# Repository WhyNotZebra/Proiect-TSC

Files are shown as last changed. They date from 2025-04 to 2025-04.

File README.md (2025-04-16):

# Proiect TSC – E-Reader Hardware

Acest proiect își propune să construiască un **e-reader open-source**, bazat pe microcontrollerul **ESP32-C6**, cu un display **e-Paper de 7.5"**, o baterie **Li-Po** reîncărcabilă și conexiuni **Wi-Fi/BLE**.  
Scopul este obținerea unui dispozitiv cu **consum de energie redus**, ideal pentru citirea de cărți și documente în format electronic.

---

## Cuprins

- [Diagrama bloc](#diagrama-bloc)
- [Bill of Materials (BOM)](#bill-of-materials-bom)
- [Descriere hardware și funcționalitate](#descriere-hardware-și-funcționalitate)
  - [Microcontroller – ESP32-C6](#microcontroller--esp32-c6)
  - [Ecran e-Paper (7.5")](#ecran-e-paper-75)
  - [Alimentare și baterie](#alimentare-și-baterie)
  - [Buton / BOOT](#buton--boot)
  - [Consum și durată baterie](#consum-și-durată-baterie)
- [Pin Mapping ESP32-C6](#pin-mapping-esp32-c6)
- [Cum să începi (Software)](#cum-să-începi-software)
- [Randări și fișiere CAD](#randări-și-fișiere-cad)
- [Observații de proiectare](#observații-de-proiectare)
- [Licență și contribuții](#licență-și-contribuții)
- [Referințe](#referințe)
- [Concluzie](#concluzie)

---

## Diagrama bloc

Fișierul **block_diagram.png** descrie schema generală a sistemului, incluzând:

- **ESP32-C6** – Microcontroller principal  
- **Ecran e-Paper** – Interfață SPI  
- **Baterie Li-Po + modul de încărcare**  
- **Conectivitate USB** pentru încărcare și date  
- **Buton/Buton BOOT** pentru interacțiunea cu utilizatorul (reset, mod debug etc.)  

---

## Bill of Materials (BOM)

Mai jos este prezentată o listă cu principalele componente folosite în proiect. Pentru toate componentele, datasheet-urile sunt indicate pentru a facilita selectarea și verificarea specificațiilor.

| Referință | Valoare / Cod | Dispozitiv / Tip | Descriere | Link / Datasheet |
|---|---|---|---|---|
| **ESP32-C6** | ESP32-C6-DevKitC-1 | Placă DevKitC-1 ESP32-C6 | Microcontroller Wi-Fi 6 + BLE 5 | [Mouser Link](https://ro.mouser.com/ProductDetail/Espressif-Systems/ESP32-C6?qs=Imq1NPwxi75noDtUpuVuWw%3D%3D)  |
| **Ecran e-Paper** | 7.5" Waveshare V2 | Interfață SPI | Afișaj E-Ink 800×480 | [Waveshare Link](https://www.waveshare.com/7.5inch-e-paper-hat.htm) |
| **Baterie Li-Po** | 3.7V / 1800mAh | Cellevia LP584174 (ex.)  | Sursă portabilă de alimentare | [Exemplu Link](https://ampul.eu/ro/baterii/5519-baterie-li-pol-150mah-37v-302025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) |
| **Modul încărcare** | TP4056 / similar | TP4056 | Încărcare baterie Li-Po via USB | [TP4056 Link](https://ro.mouser.com/ProductDetail/DFRobot/DFR0668?qs=yqaQSyyJnNgw1QAWGbVsjg%3D%3D) |
| **Regulator LDO** | AMS1117-3.3V | SOT223 / SOT25 | Stabilizator 3.3V | [AMS1117 Link](https://ro.mouser.com/ProductDetail/Seeed-Studio/105020001?qs=1%252B9yuXKSi8Cg%2Fkz%252BrjYoTQ%3D%3D) |
| **Buton push** | PBS-110 / BOOT_BTN | 6×6mm tact switch | Buton de interacțiune (reset, BOOT) | [Omron B3F Link](https://ro.mouser.com/ProductDetail/Omron-Electronics/B3FS-1095P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) |
| **Diverse** | Condensatori, rezistențe, diode TVS, conectori USB-C, etc. | - | Pentru filtre, protecție și fixare tensiune | Vezi fișierul complet BOM din repository |

---

## Descriere hardware și funcționalitate

### Microcontroller – ESP32-C6
- Oferă **conectivitate Wi-Fi 6** și **Bluetooth 5**.  
- Gestionează afișajul e-paper prin **SPI**.  
- Are GPIO-uri disponibile pentru interacțiuni suplimentare (buton, senzori etc.).  

### Ecran e-Paper (7.5")
- **Rezoluție**: 800×480 pixeli.  
- **Consum foarte redus** în mod static (menține imaginea fără consum suplimentar).  
- **Interfață SPI** pentru actualizare.  
- Ideal pentru citirea textelor mari datorită contrastului ridicat și lipsei de flicker.  

### Alimentare și baterie
- **Baterie Li-Po** de 3.7V, 1800mAh (sau altă capacitate, la alegere).  
- **Încărcare prin USB (5V)** cu modul dedicat (TP4056 sau similar).  
- **Regulator LDO (3.3V)** pentru alimentarea ESP32-C6 și a perifericelor.  

### Buton / BOOT
- Permite **resetarea** microcontrollerului, intrarea în **mod de programare** sau alte interacțiuni definite de utilizator (ex. schimbare pagină, meniu etc.).  

### Consum și durată baterie
- În mod de citire (fără actualizări frecvente), **e-paper** consumă extrem de puțin.  
- În momentul schimbării paginii (actualizare e-paper), consumul crește pentru scurt timp.  
- **Estimare durată baterie**: de la câteva zile la câteva săptămâni, în funcție de frecvența actualizărilor și de modul de somn (sleep) al ESP32-C6.  

---

## Pin Mapping ESP32-C6

Tabelul de mai jos prezintă pinii importanți folosiți în proiect pentru conectarea ecranului e-paper și a butonului:

| Funcționalitate | Pin ESP32-C6  | Descriere |
|---|---|---|
| **SPI CLK** | GPIO6 | Semnal de ceas SPI |
| **SPI MOSI** | GPIO7 | Linie de date |
| **E-Paper CS**  | GPIO10 | Chip Select display |
| **E-Paper DC**  | GPIO5 | Selectare date/command |
| **E-Paper RST** | GPIO4 | Reset pentru e-paper |
| **E-Paper BUSY**| GPIO3 | Linie READY (ocupat) |
| **Buton** | GPIO0/1 etc. | Buton reset/interacțiune  |
| **UART TX/RX**  | GPIO21/20 | Debug (opțional) |

> **Notă**: Pinii pot fi modificați în funcție de necesități. Tabelul de mai sus reprezintă doar un exemplu.  

---

## Cum să începi (Software)

1. **Clonează repository-ul**:
    ```bash
    git clone https://github.com/WhyNotZebra/Proiect-TSC.git
    ```

2. **Instalează suportul** pentru **ESP32-C6** în mediul de dezvoltare (Arduino IDE sau PlatformIO).  
   - Asigură-te că ai ultima versiune de **ESP32 Boards** în Arduino IDE / PlatformIO.

3. **Deschide folderul** cu codul sursă (ex. `software/`) în Arduino IDE / PlatformIO.  
   - Exemple de librării necesare:  
     - `Adafruit-GFX`  
     - `GxEPD2` (sau altă librărie dedicată e-paper)

4. **Selectează placa** corespunzătoare (ex. *ESP32C6 DevKit*) și conectează placa prin USB.

5. **Încărcă (upload)** sketch-ul pe microcontroller.

6. **Monitorizează** comportamentul în *Serial Monitor* (viteză tipică: 115200 bps) pentru log-uri de debug.

---

## Randări și fișiere CAD

- Folderul `Images/` conține randări 3D (`render_device.png`, `render_pcb.png`) și diagrama bloc (`block_diagram.png`).  
- Fișierele de design (Eagle, KiCad sau Fusion 360 PCB) se află în folderul `hardware/`.  
- Gerbers și BOM detaliată pentru fabricație se găsesc în `hardware/output/`.  

---

## Observații de proiectare

- **Consum redus**: e-paper-ul menține imaginea fără consum suplimentar, deci microcontrollerul poate intra des în mod *sleep*.  
- **Protecția la încărcare**: modului de încărcare TP4056 i se pot adăuga circuite de protecție suplimentare (TVS, diode) pe portul USB-C.  
- **Dimensiuni și ergonomie**: poziționarea butoanelor de navigare la îndemână îmbunătățește experiența de lectură.  

---

## Licență și contribuții

Acest proiect este disponibil sub licența **MIT** (sau alta specificată în repository).  
Orice contribuții (pull request-uri, issue-uri) sunt încurajate, fie că este vorba de:
- Optimizări hardware  
- Îmbunătățiri de cod  
- Documentație suplimentară  
- Orice alt element care poate aduce valoare proiectului  

---

## Referințe

- [Documentația oficială ESP32-C6](#)  
- [TP4056 Battery Charger Datasheet](#)  

---

## Concluzie

Proiectul **TSC – E-Reader Hardware** oferă o platformă completă pentru a crea un dispozitiv de citire electronică cu autonomie ridicată și hardware flexibil.  
Fie că vrei să înveți, să experimentezi sau să creezi propriul tău eReader personalizat, acest repository îți pune la dispoziție:

- **Schemă și layout PCB**  
- **BOM detaliată**  
- **Cod sursă configurabil**  
- **Documentație pas cu pas**

Spor la **cafelutza**!

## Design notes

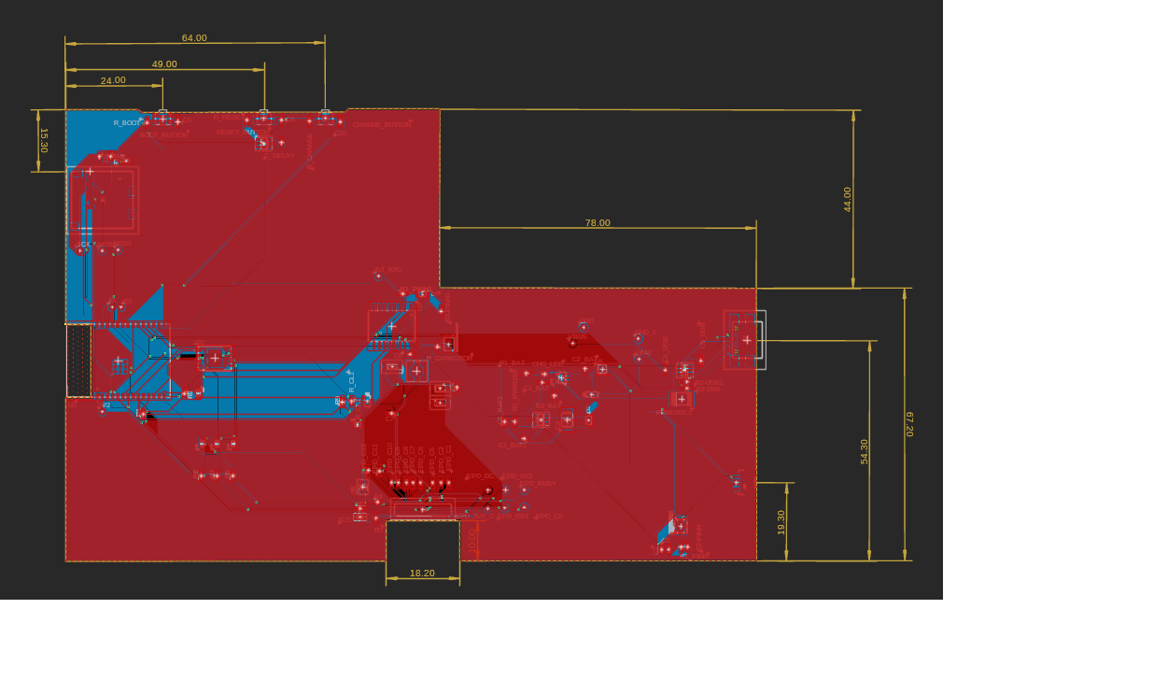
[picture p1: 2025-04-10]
Images/BRD.png

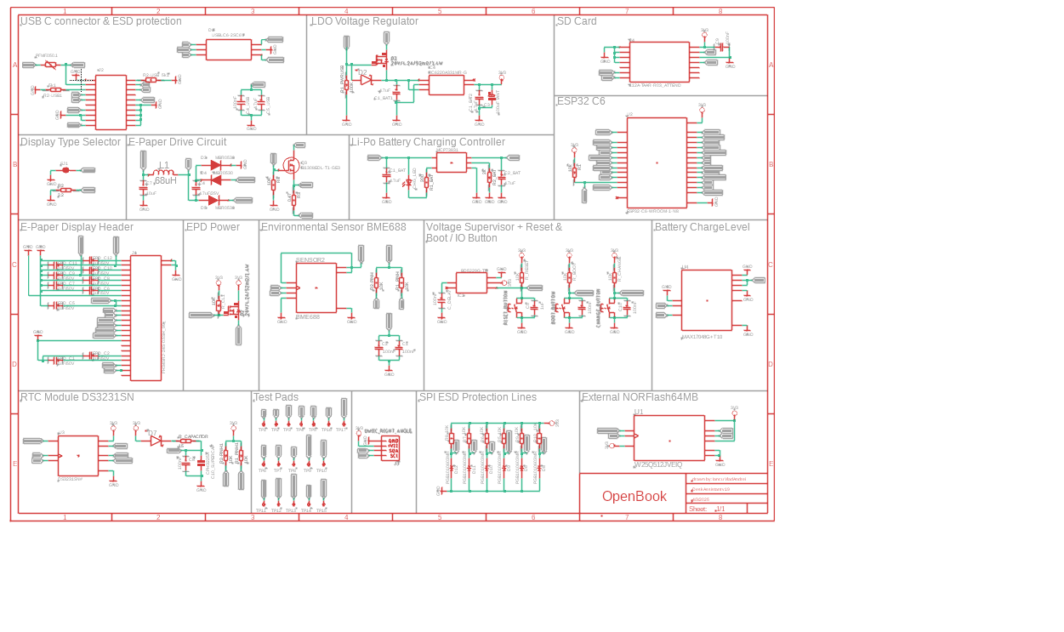
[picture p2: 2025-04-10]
Images/SCH.png

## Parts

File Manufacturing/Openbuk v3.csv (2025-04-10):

Part | Value | Device | Footprint Name | Detailed Description
BOOT_BUTTON |  | BUTTON_CUSYOMV1 | MYBUTTON
C1 | 100nF | EAGLE-LTSPICE_CC0402 | EAGLE-LTSPICE_C0402 | CAPACITOR, European symbol
C1_BAT | 4.7uF | EAGLE-LTSPICE_CC0402 | EAGLE-LTSPICE_C0402 | CAPACITOR, European symbol
C1_BAT1 | 4.7uF | EAGLE-LTSPICE_CC0402 | EAGLE-LTSPICE_C0402 | CAPACITOR, European symbol
C1_BAT2 | 4.7uF | EAGLE-LTSPICE_CC0402 | EAGLE-LTSPICE_C0402 | CAPACITOR, European symbol
C2 | 100nF | EAGLE-LTSPICE_CC0402 | EAGLE-LTSPICE_C0402 | CAPACITOR, European symbol
C2_BAT | 4.7uF | EAGLE-LTSPICE_CC0402 | EAGLE-LTSPICE_C0402 | CAPACITOR, European symbol
C3 | 100uF TANT | RCL_CPOL-EUCT3528 | RCL_CT3528 | POLARIZED CAPACITOR, European symbol
C4 | 4.7uF/25V | EAGLE-LTSPICE_CC0402 | EAGLE-LTSPICE_C0402 | CAPACITOR, European symbol
C4_USB | 100nF | EAGLE-LTSPICE_CC0402 | EAGLE-LTSPICE_C0402 | CAPACITOR, European symbol
C5 | 1uF | EAGLE-LTSPICE_CC0402 | EAGLE-LTSPICE_C0402 | CAPACITOR, European symbol
C5_USB | 4.7uF | EAGLE-LTSPICE_CC0402 | EAGLE-LTSPICE_C0402 | CAPACITOR, European symbol
C6 | 100nF | EAGLE-LTSPICE_CC0402 | EAGLE-LTSPICE_C0402 | CAPACITOR, European symbol
C7 | 10uF | EAGLE-LTSPICE_CC0402 | EAGLE-LTSPICE_C0402 | CAPACITOR, European symbol
C8 | 100nF | EAGLE-LTSPICE_CC0402 | EAGLE-LTSPICE_C0402 | CAPACITOR, European symbol
C9 | 100nF | EAGLE-LTSPICE_CC0402 | EAGLE-LTSPICE_C0402 | CAPACITOR, European symbol
C10 | 100nF | EAGLE-LTSPICE_CC0402 | EAGLE-LTSPICE_C0402 | CAPACITOR, European symbol
C10_SUPERCAP | CPH3225A | CPH3225A | CAPCP3225X100N | Cap 0.011F 3.3V 1210 Flat Check availability
CHANGE_BUTTON |  | BUTTON_CUSYOMV1 | MYBUTTON
CHG_LED |  | ADAFRUIT_LEDCHIP-LED0603 | ADAFRUIT_CHIP-LED0603 | LED
C_DELAY | 100nF | EAGLE-LTSPICE_CC0402 | EAGLE-LTSPICE_C0402 | CAPACITOR, European symbol
D1 | USBLC6-2SC6Y | USBLC6-2SC6Y | SOT95P280X145-6N | Low Cap. ESD Protection Auto SOT-23-6 STMicroelectronics USBLC6-2SC6Y, Dual Uni-Directional TVS Diode Array, 6-Pin SOT-23
D2 | SD0805S020S1R0 | ESP32_WROVER_AVX---SD0805S020S1R0_AVX_SD0805S020S1R0_0_0AVX_SD0805S020S1R0_0_0 | ESP32_WROVER_AVX---SD0805S020S1R0_AVX_SD0805S020S1R0_0 | Schottky Barrier Rectifier Diode
D3 | MBR0530 | MBR0530 | SOD3716X135N | ON SEMICONDUCTOR - MBR0530 - DIODE, SCHOTTKY, 0.5A, 30V, SOD-123
D4 | MBR0530 | MBR0530 | SOD3716X135N | ON SEMICONDUCTOR - MBR0530 - DIODE, SCHOTTKY, 0.5A, 30V, SOD-123
D5 | MBR0530 | MBR0530 | SOD3716X135N | ON SEMICONDUCTOR - MBR0530 - DIODE, SCHOTTKY, 0.5A, 30V, SOD-123
D6 | PGB1010603MR | PGB1010603MR | DIOC1608X36N | Check availability
D7 | SD0805S020S1R0 | ESP32_WROVER_AVX---SD0805S020S1R0_AVX_SD0805S020S1R0_0_0AVX_SD0805S020S1R0_0_0 | ESP32_WROVER_AVX---SD0805S020S1R0_AVX_SD0805S020S1R0_0 | Schottky Barrier Rectifier Diode
D8 | PGB1010603MR | PGB1010603MR | DIOC1608X36N | Check availability
D9 | PGB1010603MR | PGB1010603MR | DIOC1608X36N | Check availability
D10 | PGB1010603MR | PGB1010603MR | DIOC1608X36N | Check availability
D11 | PGB1010603MR | PGB1010603MR | DIOC1608X36N | Check availability
D12 | PGB1010603MR | PGB1010603MR | DIOC1608X36N | Check availability
EPD_C1 | 1uF/50V | EAGLE-LTSPICE_CC0402 | EAGLE-LTSPICE_C0402 | CAPACITOR, European symbol
EPD_C2 | 1uF/50V | EAGLE-LTSPICE_CC0402 | EAGLE-LTSPICE_C0402 | CAPACITOR, European symbol
EPD_C5 | 1uF/50V | EAGLE-LTSPICE_CC0402 | EAGLE-LTSPICE_C0402 | CAPACITOR, European symbol
EPD_C6 | 1uF/50V | EAGLE-LTSPICE_CC0402 | EAGLE-LTSPICE_C0402 | CAPACITOR, European symbol
EPD_C7 | 1uF/50V | EAGLE-LTSPICE_CC0402 | EAGLE-LTSPICE_C0402 | CAPACITOR, European symbol
EPD_C8 | 1uF/50V | EAGLE-LTSPICE_CC0402 | EAGLE-LTSPICE_C0402 | CAPACITOR, European symbol
EPD_C9 | 1uF/50V | EAGLE-LTSPICE_CC0402 | EAGLE-LTSPICE_C0402 | CAPACITOR, European symbol
EPD_C10 | 1uF/50V | EAGLE-LTSPICE_CC0402 | EAGLE-LTSPICE_C0402 | CAPACITOR, European symbol
EPD_C11 | 1uF/50V | EAGLE-LTSPICE_CC0402 | EAGLE-LTSPICE_C0402 | CAPACITOR, European symbol
EPD_C12 | 1uF/50V | EAGLE-LTSPICE_CC0402 | EAGLE-LTSPICE_C0402 | CAPACITOR, European symbol
IC1 | BD5229G-TR | BD5229G-TR | SOT95P280X125-5N | Voltage Detector with Adjustable Delay Time: CMOS processes are utilized to develop high precision, low current consumption CMOS reset ICs that allow arbitrary setting of the delay time. The extensive lineup includes both Nch Open Drain and CMOS output types in a wide range of detection voltages (from 2.3V to 6.0V, in 0.1V steps), enabling selection of the ideal solution based on customer requirements. In addition, the entire series is of course both lead-free and RoHS-compliant.
IC4 | XC6220A331MR-G | XC6220A331MR-G | SOT95P280X120-5N | LDO Voltage Regulators
J1 | FH34SRJ-24S-0.5SH_99_ | FH34SRJ-24S-0.5SH_99_ | FH34SRJ24S05SH99 | 24 Position FFC, FPC Connector Contacts, Top and Bottom 0.020 (0.50mm) Surface Mount, Right Angle"
J2 |  | SAMACSYS_PARTS_USB4110-GF-A | SAMACSYS_PARTS_USB4110GFA | CONN USB 2.0 TYPE-C R/A SMT
J3 | QWIIC_RIGHT_ANGLE | QWIIC_CONNECTORJS-1MM | JST04_1MM_RA | SparkFun I2C Standard Qwiic Connector
J4 | 112A-TAAR-R03_ATTEND | 112A-TAAR-R03_ATTEND | 112ATAARR03ATTEND | Micro SD Card Socket, Push-Push Type, Top Mount, SMT, H=1.83mm, 10u
L1 | 68uH | 744043680IND_4828-WE-TPC_WRE | IND_4828-WE-TPC_WRE
MCP73831 |  | ESP32_WROVER_SPARKFUN-IC-POWER_MCP73831 | ESP32_WROVER_SPARKFUN-IC-POWER_SOT23-5 | MCP73831T Li-Ion, Li-Pol Controller
PFMF.050.1 |  | ESP32C6_VARISTORCN1812 | ESP32C6_VARISTOR_CT/CN1812 | VARISTOR
Q1 | 20V/4.2A/52mO/1.4W | ESP32_WROVER_SPARKFUN-DISCRETESEMI_MOSFET_PCH-DMG2305UX-7 | ESP32_WROVER_SPARKFUN-DISCRETESEMI_SOT23-3 | P-channel MOSFETs
Q2 | 20V/4.2A/52mO/1.4W | ESP32_WROVER_SPARKFUN-DISCRETESEMI_MOSFET_PCH-DMG2305UX-7 | ESP32_WROVER_SPARKFUN-DISCRETESEMI_SOT23-3 | P-channel MOSFETs
Q3 | SI1308EDL-T1-GE3 | SI1308EDL-T1-GE3 | SOT65P210X110-3N | MOSFET N-Ch 30V 1.5A TrenchFET SC70 Vishay Si1308EDL-T1-GE3 N-channel MOSFET Transistor, 1.5 A, 30 V, 3-Pin SC-70
R1 | 10k | ESP32_WROVER_EAGLE-LTSPICE_RR0402 | ESP32_WROVER_EAGLE-LTSPICE_R0402 | RESISTOR, European symbol
R1_BAT | 200 | ESP32_WROVER_EAGLE-LTSPICE_RR0402 | ESP32_WROVER_EAGLE-LTSPICE_R0402 | RESISTOR, European symbol
R1_PINH | 10K | ESP32_WROVER_EAGLE-LTSPICE_RR0402 | ESP32_WROVER_EAGLE-LTSPICE_R0402 | RESISTOR, European symbol
R1_PINH1 | 10K | ESP32_WROVER_EAGLE-LTSPICE_RR0402 | ESP32_WROVER_EAGLE-LTSPICE_R0402 | RESISTOR, European symbol
R1_PWRUSB | 100K | ESP32_WROVER_EAGLE-LTSPICE_RR0402 | ESP32_WROVER_EAGLE-LTSPICE_R0402 | RESISTOR, European symbol
R2 | 2.2 | ESP32_WROVER_EAGLE-LTSPICE_RR0402 | ESP32_WROVER_EAGLE-LTSPICE_R0402 | RESISTOR, European symbol
R2-PINH | 10K | ESP32_WROVER_EAGLE-LTSPICE_RR0402 | ESP32_WROVER_EAGLE-LTSPICE_R0402 | RESISTOR, European symbol
R2-PINH1 | 10K | ESP32_WROVER_EAGLE-LTSPICE_RR0402 | ESP32_WROVER_EAGLE-LTSPICE_R0402 | RESISTOR, European symbol
R2-USB | 5k1 | ESP32_WROVER_EAGLE-LTSPICE_RR0402 | ESP32_WROVER_EAGLE-LTSPICE_R0402 | RESISTOR, European symbol
R2-USB1 | 5k1 | ESP32_WROVER_EAGLE-LTSPICE_RR0402 | ESP32_WROVER_EAGLE-LTSPICE_R0402 | RESISTOR, European symbol
R2_BAT | 2k | ESP32_WROVER_EAGLE-LTSPICE_RR0402 | ESP32_WROVER_EAGLE-LTSPICE_R0402 | RESISTOR, European symbol
R3 | 0.47 | ESP32_WROVER_EAGLE-LTSPICE_RR0402 | ESP32_WROVER_EAGLE-LTSPICE_R0402 | RESISTOR, European symbol
R4 | 10K | ESP32_WROVER_EAGLE-LTSPICE_RR0402 | ESP32_WROVER_EAGLE-LTSPICE_R0402 | RESISTOR, European symbol
R5 | 10K | ESP32_WROVER_EAGLE-LTSPICE_RR0402 | ESP32_WROVER_EAGLE-LTSPICE_R0402 | RESISTOR, European symbol
R6 | 10K | ESP32_WROVER_EAGLE-LTSPICE_RR0402 | ESP32_WROVER_EAGLE-LTSPICE_R0402 | RESISTOR, European symbol
R7 | 10K | ESP32_WROVER_EAGLE-LTSPICE_RR0402 | ESP32_WROVER_EAGLE-LTSPICE_R0402 | RESISTOR, European symbol
R8 | 10K | ESP32_WROVER_EAGLE-LTSPICE_RR0402 | ESP32_WROVER_EAGLE-LTSPICE_R0402 | RESISTOR, European symbol
R9 | 10K | ESP32_WROVER_EAGLE-LTSPICE_RR0402 | ESP32_WROVER_EAGLE-LTSPICE_R0402 | RESISTOR, European symbol
R10 | 10K | ESP32_WROVER_EAGLE-LTSPICE_RR0402 | ESP32_WROVER_EAGLE-LTSPICE_R0402 | RESISTOR, European symbol
RESET_BUTTON |  | BUTTON_CUSYOMV1 | MYBUTTON
R_BOOT | 10K | ESP32_WROVER_EAGLE-LTSPICE_RR0402 | ESP32_WROVER_EAGLE-LTSPICE_R0402 | RESISTOR, European symbol
R_CAPACITOR | 15 | ESP32_WROVER_EAGLE-LTSPICE_RR0402 | ESP32_WROVER_EAGLE-LTSPICE_R0402 | RESISTOR, European symbol
R_CHANGE | 10K | ESP32_WROVER_EAGLE-LTSPICE_RR0402 | ESP32_WROVER_EAGLE-LTSPICE_R0402 | RESISTOR, European symbol
R_CL1 | 10K | ESP32_WROVER_EAGLE-LTSPICE_RR0402 | ESP32_WROVER_EAGLE-LTSPICE_R0402 | RESISTOR, European symbol
R_RESET | 10K | ESP32_WROVER_EAGLE-LTSPICE_RR0402 | ESP32_WROVER_EAGLE-LTSPICE_R0402 | RESISTOR, European symbol
SENSOR2 | BME688 | ESP32_WROVER_BME680_BME680 | ESP32_WROVER_BME680_PSON80P300X300X100-8N | Integrated Environmental Unit
SJ1 |  | SJ | ESP32_WROVER_EAGLE-LTSPICE_R0402 | SMD solder JUMPER
TP1 | TPTP20R | TPTP20R | TP20R | Test pad
TP2 | TPTP20R | TPTP20R | TP20R | Test pad
TP3 | TPTP20R | TPTP20R | TP20R | Test pad
TP4 | TPTP20R | TPTP20R | TP20R | Test pad
TP5 | TPTP20R | TPTP20R | TP20R | Test pad
TP6 | TPTP20R | TPTP20R | TP20R | Test pad
TP7 | TPTP20R | TPTP20R | TP20R | Test pad
TP8 | TPTP20R | TPTP20R | TP20R | Test pad
TP9 | TPTP20R | TPTP20R | TP20R | Test pad
TP10 | TPTP20R | TPTP20R | TP20R | Test pad
TP11 | TPTP20R | TPTP20R | TP20R | Test pad
TP12 | TPTP20R | TPTP20R | TP20R | Test pad
TP13 | TPTP20R | TPTP20R | TP20R | Test pad
TP14 | TPTP20R | TPTP20R | TP20R | Test pad
TP15 | TPTP20R | TPTP20R | TP20R | Test pad
TP16 | TPTP20R | TPTP20R | TP20R | Test pad
TP17 | TPTP20R | TPTP20R | TP20R | Test pad
U1 | W25Q512JVEIQ | W25Q512JVEIQ | SON127P600X800X80-9N | Check availability
U2 | ESP32-C6-WROOM-1-N8 | ESP32-C6-WROOM-1-N8 | XCVR_ESP32-C6-WROOM-1-N8 | Check availability
U3 | DS3231SN# | DS3231SN# | SOIC127P1032X265-16N | Real Time Clock Serial 16-Pin SOIC W T/R Check availability
U4 | MAX17048G+T10 | MAX17048G+T10 | SON50P200X200X80-9N | Check availability

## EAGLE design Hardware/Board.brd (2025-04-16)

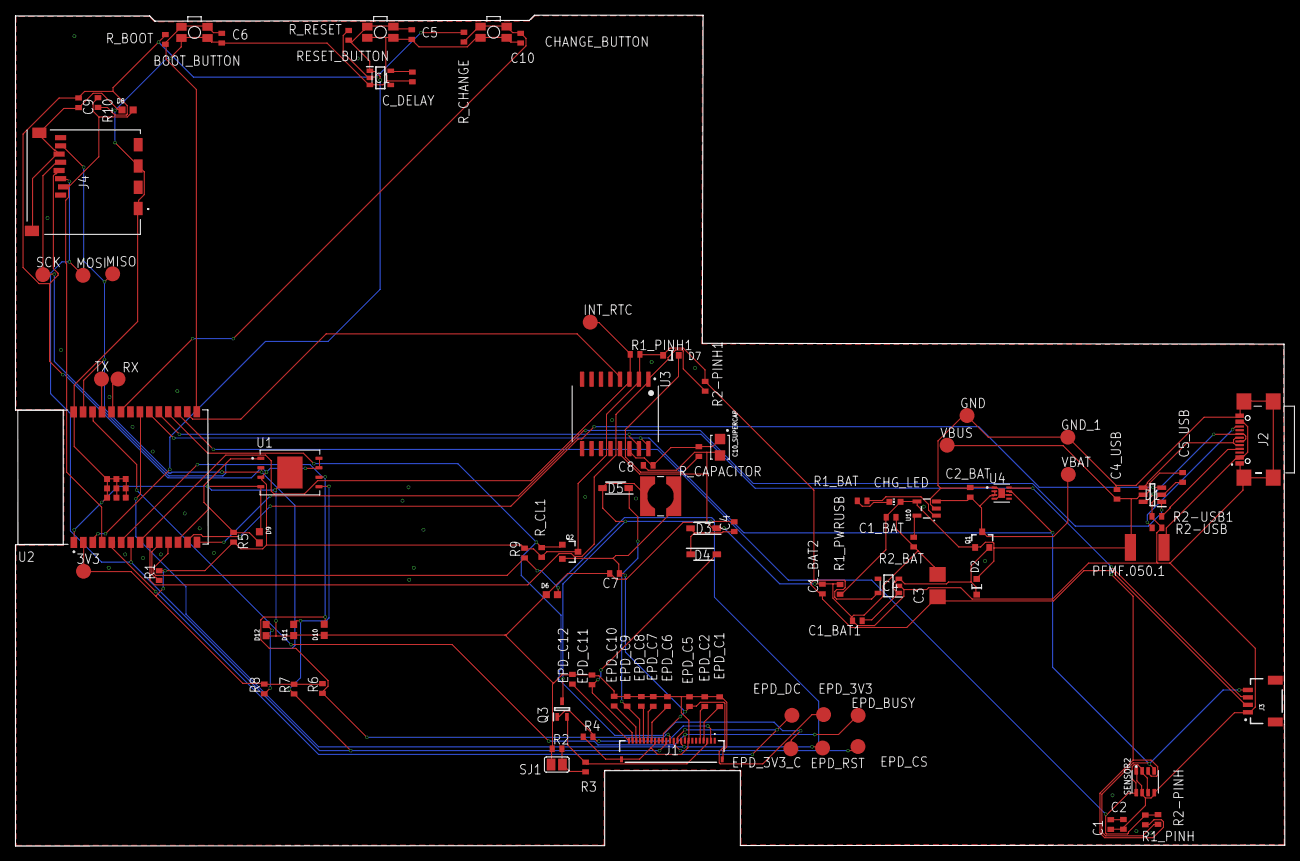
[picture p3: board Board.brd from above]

Board: 2 copper layers, 170.2 x 111.4 mm, 103 parts (0 on the bottom side), 56 nets.

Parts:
3V3: TPTP20R; TP20R
BOOT_BUTTON: BUTTON_CUSYOMV1; MYBUTTON
C1: 100uF; EAGLE-LTSPICE_C0402
C1_BAT, C2_BAT: 4.7uF; ESP32_WROVER_EAGLE-LTSPICE_C0402
C1_BAT1, C1_BAT2, C5_USB: 4.7uF; EAGLE-LTSPICE_C0402
C2, C4_USB, C8, C9: 100nF; EAGLE-LTSPICE_C0402
C3: 100uF TANT; RCL_CT3528
C4: 4.7uF/25V; ESP32_WROVER_EAGLE-LTSPICE_C0402
C5: 1uF; ESP32_WROVER_EAGLE-LTSPICE_C0402
C6, C10: 100nF; ESP32_WROVER_EAGLE-LTSPICE_C0402
C7: 10uF; ESP32_WROVER_EAGLE-LTSPICE_C0402
C10_SUPERCAP: CPH3225A; CAPCP3225X100N
CHANGE_BUTTON: BUTTON_CUSYOMV1; MYBUTTON
CHG_LED: ADAFRUIT_CHIP-LED0603
C_DELAY: 100nF; ESP32_WROVER_EAGLE-LTSPICE_C0402
D1: USBLC6-2SC6Y; SOT95P280X145-6N
D2, D7: ESP32_WROVER_AVX---SD0805S020S1R0_AVX_SD0805S020S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; ESP32_WROVER_AVX---SD0805S020S1R0_AVX_SD0805S020S1R0_0
D3, D4, D5: MBR0530; SOD3716X135N
D6, D8, D9, D10, D11, D12: PGB1010603MR; DIOC1608X36N
EPD_3V3, EPD_3V3_C: TPTP20R; TP20R
EPD_BUSY: TPTP20R; TP20R
EPD_C1, EPD_C2, EPD_C6, EPD_C7, EPD_C8, EPD_C9, EPD_C10, EPD_C11, EPD_C12: 1uF/50V; ESP32_WROVER_EAGLE-LTSPICE_C0402
EPD_C5: 0.1uF/50V; ESP32_WROVER_EAGLE-LTSPICE_C0402
EPD_CS: TPTP20R; TP20R
EPD_DC: TPTP20R; TP20R
EPD_RST: TPTP20R; TP20R
GND: TPTP20R; TP20R
GND_1: TPTP20R; TP20R
IC1: BD5229G-TR; SOT95P280X125-5N
IC4: XC6220A331MR-G; SOT95P280X120-5N
INT_RTC: TPTP20R; TP20R
J1: FH34SRJ-24S-0.5SH_99_; FH34SRJ24S05SH99
J2: SAMACSYS_PARTS_USB4110-GF-A; SAMACSYS_PARTS_USB4110GFA
J3: QWIIC_RIGHT_ANGLE; JST04_1MM_RA
J4: 112A-TAAR-R03_ATTEND; 112ATAARR03ATTEND
L1: 744043680IND_4828-WE-TPC_WRE; IND_4828-WE-TPC_WRE
MISO: TPTP20R; TP20R
MOSI: TPTP20R; TP20R
PFMF.050.1: ESP32C6_VARISTORCN1812; ESP32C6_VARISTOR_CT/CN1812
Q1, Q2: 20V/4.2A/52mΩ/1.4W; ESP32_WROVER_SPARKFUN-DISCRETESEMI_SOT23-3
Q3: SI1308EDL-T1-GE3; SOT65P210X110-3N
R1, R1_PINH, R1_PINH1, R2-PINH, R2-PINH1, R4, R5, R6, R7, R8, R9, R10: 10K; ESP32_WROVER_EAGLE-LTSPICE_R0402
R1_BAT: 200; ESP32_WROVER_EAGLE-LTSPICE_R0402
R1_PWRUSB: 100k; ESP32_WROVER_EAGLE-LTSPICE_R0402
R2: 2.2; ESP32_WROVER_EAGLE-LTSPICE_R0402
R2-USB: 5K1; ESP32_WROVER_EAGLE-LTSPICE_R0402
R2-USB1: 5k1; ESP32_WROVER_EAGLE-LTSPICE_R0402
R2_BAT: 2K; ESP32_WROVER_EAGLE-LTSPICE_R0402
R3: 0.47; ESP32_WROVER_EAGLE-LTSPICE_R0402
RESET_BUTTON: BUTTON_CUSYOMV1; MYBUTTON
RX: TPTP20R; TP20R
R_BOOT: 10K; ESP32_WROVER_EAGLE-LTSPICE_R0402
R_CAPACITOR: 15; ESP32_WROVER_EAGLE-LTSPICE_R0402
R_CHANGE: 10K; ESP32_WROVER_EAGLE-LTSPICE_R0402
R_CL1: 10K; ESP32_WROVER_EAGLE-LTSPICE_R0402
R_RESET: 10K; ESP32_WROVER_EAGLE-LTSPICE_R0402
SCK: TPTP20R; TP20R
SENSOR2: ESP32_WROVER_BME680_BME680; ESP32_WROVER_BME680_PSON80P300X300X100-8N
SJ1: SJ
TX: TPTP20R; TP20R
U1: W25Q512JVEIQ; SON127P600X800X80-9N
U2: ESP32-C6-WROOM-1-N8; XCVR_ESP32-C6-WROOM-1-N8
U3: DS3231SN#; SOIC127P1032X265-16N
U4: MAX17048G+T10; SON50P200X200X80-9N
U10: ESP32_WROVER_SPARKFUN-IC-POWER_MCP73831; ESP32_WROVER_SPARKFUN-IC-POWER_SOT23-5
VBAT: TPTP20R; TP20R
VBUS: TPTP20R; TP20R

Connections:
3V3: 3V3.TP, C1_BAT2.1, C3.+, C9.1, D7.2, IC1.2, IC4.5, J3.2, J4.P4, Q2.3, R1.2, R1_PINH1.2, R2-PINH1.2, R5.2, R6.2, R7.2, R8.2, R9.2, R10.2, R_BOOT.2, R_CHANGE.2, R_CL1.2, R_RESET.2, U1.3, U1.7, U1.8, U2.2, U3.2
32KHZ: R2-PINH1.1, U2.9, U3.1
DN: D1.4, J2.A7, J2.B7
DP: D1.6, J2.A6, J2.B6
EPD_3V3: C7.1, EPD_3V3.TP, EPD_C5.1, J1.15, J1.16, L1.2, Q2.2
EPD_3V3_C: EPD_3V3_C.TP, Q2.1, R_CL1.1, U2.18
EPD_BUSY: EPD_BUSY.TP, J1.9, U2.26
EPD_CS: D6.2, EPD_CS.TP, J1.12, R9.1, U2.11
EPD_DC: EPD_DC.TP, J1.11, U2.5
EPD_RST: EPD_RST.TP, J1.10, U2.21
FLASH_CS: D9.2, R5.1, U1.1, U2.12
GDR: J1.2, Q3.1, R4.2
GND: BOOT_BUTTON.1, BOOT_BUTTON.2, C1.2, C1_BAT.2, C1_BAT1.2, C1_BAT2.2, C2.2, C2_BAT.2, C3.-, C4_USB.2, C5.2, C5_USB.2, C6.2, C7.2, C8.2, C9.2, C10.2, C10_SUPERCAP.2, CHANGE_BUTTON.1, CHANGE_BUTTON.2, C_DELAY.2, D1.2, D3.1, D6.1, D8.1, D9.1, D10.1, D11.1, D12.1, EPD_C1.2, EPD_C2.2, EPD_C5.2, EPD_C6.2, EPD_C7.2, EPD_C8.2, EPD_C9.2, EPD_C10.2, EPD_C11.2, EPD_C12.2, GND.TP, GND_1.TP, IC1.3, IC4.2, J1.8, J1.17, J1.MP1, J1.MP2, J2.A1, J2.A12, J2.B1, J2.B12, J2.MP1, J2.MP2, J2.MP3, J2.MP4, J3.1, J4.G1, J4.G2, J4.G3, J4.G4, J4.P6, R1_PWRUSB.1, R2.1, R2-USB.2, R2-USB1.1, R2_BAT.1, R4.1, RESET_BUTTON.1, RESET_BUTTON.2, SENSOR2.1, SENSOR2.5, SENSOR2.7, SJ1.1, U1.4, U1.9, U2.1, U2.28, U2.29_1, U2.29_2, U2.29_3, U2.29_4, U2.29_5, U2.29_6, U2.29_7, U2.29_8, U2.29_9, U3.13, U4.1, U4.4, U4.6, U4.9, U10.2
GPIO8: R1.1, U2.10
I2C_PW: R1_PINH.2, R2-PINH.2, SENSOR2.2, SENSOR2.6, SENSOR2.8, U2.17
INT_RTC: INT_RTC.TP, R1_PINH1.1, U2.8, U3.3
IO/BOOT: BOOT_BUTTON.3, BOOT_BUTTON.4, C6.1, R_BOOT.1, U2.15
IO/CHANGE: C10.1, CHANGE_BUTTON.3, CHANGE_BUTTON.4, R_CHANGE.1, U2.23
MISO: D12.2, J4.P7, MISO.TP, R8.1, U1.2, U2.27
MOSI: D11.2, J1.14, J4.P3, MOSI.TP, R7.1, U1.5, U2.7
unnamed: C1_BAT1.1, D2.1, IC4.1, IC4.3, Q1.2
unnamed: J2.B5, R2-USB.1
unnamed: R2_BAT.2, U10.5
unnamed: J2.A5, R2-USB1.2
unnamed: C1.1, C2.1
unnamed: C4.1, D3.2, D4.1
unnamed: C_DELAY.1, IC1.5
unnamed: CHG_LED.C, R1_BAT.1
unnamed: R1_BAT.2, U10.1
unnamed: EPD_C2.1, J1.5
unnamed: EPD_C1.1, J1.4
unnamed: EPD_C12.1, J1.24
unnamed: D7.1, R_CAPACITOR.1
unnamed: EPD_C10.1, J1.22
unnamed: EPD_C8.1, J1.20
unnamed: EPD_C7.1, J1.19
unnamed: EPD_C6.1, J1.18
PREVGH: D5.1, EPD_C9.1, J1.21
PREVGL: D4.2, EPD_C11.1, J1.23
RESE: J1.3, Q3.2, R3.2
RESE': R2.2, R3.1, SJ1.2
RESET: C5.1, IC1.1, RESET_BUTTON.3, RESET_BUTTON.4, R_RESET.1, U2.3
RTC_RST: U2.16, U3.4
RX: RX.TP, U2.24
SCK: D10.2, J1.13, J4.P5, R6.1, SCK.TP, U1.6, U2.6
SCL: J3.4, R2-PINH.1, SENSOR2.4, U2.20, U3.16, U4.7
SDA: J3.3, R1_PINH.1, SENSOR2.3, U2.19, U3.15, U4.8
SRC: C4.2, D5.2, L1.1, Q3.3
SS_SD: D8.2, J4.P2, R10.1, U2.4
TX: TX.TP, U2.25
USB_D+: D1.1, U2.14
USB_D-: D1.3, U2.13
VBAT: C2_BAT.1, Q1.3, U4.2, U4.3, U10.3, VBAT.TP
VBUS: C1_BAT.1, C4_USB.1, C5_USB.1, CHG_LED.A, D1.5, D2.2, PFMF.050.1.2, Q1.1, R1_PWRUSB.2, U10.4, VBUS.TP
VRTC: C8.1, C10_SUPERCAP.1, R_CAPACITOR.2, U3.14
VUSB: J2.A4, J2.A9, J2.B4, J2.B9, PFMF.050.1.1

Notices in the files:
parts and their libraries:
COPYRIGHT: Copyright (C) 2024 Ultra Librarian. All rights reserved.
